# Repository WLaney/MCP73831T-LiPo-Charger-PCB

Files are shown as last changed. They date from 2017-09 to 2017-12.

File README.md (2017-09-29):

# MCP73831T-LiPo-Charger-PCB

This is a breakout board for the MCP73831T IC. The MCP73831T is a LiPo charging chip.

This board was desgined as part of the Sharkduino Project at The College of William and Mary, more information can be found at [sharkduino.com](http://www.sharkduino.com)

## License Information

This hardware is released under [Creative Commons ShareAlike 4.0 International](https://creativecommons.org/licenses/by-sa/4.0/).

It is derived from the [SparkFun LiPo Charger Basic](https://github.com/sparkfun/Lipo_Charger_Basic-microUSB/tree/V_1.0), desgined by SparkFun Electronics.

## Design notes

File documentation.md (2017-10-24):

# MCP73831T LiPo Charger

This board was designed by William Laney as part of the College of William and Mary's physics undergraduate research, 2017. 
Questions or concerns can be directed to William Laney at welaney@email.wm.edu

This is a LiPo battery chargining board based on the  MCP73831T IC. The MCP73831T  is a charging chip for 3.3V single cell lipo batteries. 

The chip is connected to a red LED. The LED is on while the battery is charging and turns off when the battery has completed its charge cycle.

Power enters the through a microUSB port on one side of the board, the LiPo to be charged in plugged into a JPL connector on the bottom of the board. The microUSB port and JPl connector are on oppistie sides of the board to more realistily simulate the set up of the Sharkduino system it is being developed for.

On the silk screen, IN corrosponds to the voltage from the microUSB port. OUT is voltage from the battery. GND is ground

All traces on this board are 0.016" and the vias have 0.034" drill holes. This is more than sufficient to handle the current through the traces. Right angles in the trace are avoid to help ensure data integrity.

Decoupling capacitors were added as near to the chips as possible to minimize noise to the chips. This is detailed in the relevant data sheets.

0805 package size is used for all passive components. This size was selected because I believe it to be a good compromise between size and ease of placement.

On October 5, 2017 six boards were ordered from OSHpark for \$4.90. This corresponds to \$0.81 per board.

## Assembily Information

Assemblie steps:
(please note that these steps represent what I beilive to be the optimal order of operations. They may not be. Addionaly not all boards were assembled in this way as I expermented with the order)

1. Applie solder paste for MCP73831T
2. Applie solder past for passive components
3. Applie solder past for microUSB port
4. Place MCP73831T
5. Place passive components
   * Start with components closest to the board and work inward
6. Place full board into solder reflow oven
7. Wipe down with isopropal alchohal 
8. Hand solder JPL connector onto the bottom of the board
9. Hand solder the through hole portions of the microUSB port
10. Check if board is shorted between GND and IN/OUT

## Notes/Feature Requests

*this information is subject to change with as more boards are assembled*

The microUSB port on the BOM does not match the land pattern on the board

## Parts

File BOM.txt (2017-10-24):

component/value, size, quanity, digikey part number
--------------------------------------------------------
MCP73831 IC, SC-74A/SOT-753, 1, MCP73831T-2ATI/OTCT-ND
JST Male, 2mm, 1, 455-1749-1-ND
USB micro SMD+TH, NA, 1, 609-4618-1-ND
4.7uF capacitor, 0805, 2, 490-3335-1-ND
330 resistor, 0805, 1, 311-330CRCT-ND
2k resistor, 0805, 1, 311-2.00KCRCT-ND
Red LED, 0603, 1, 754-1122-1-ND

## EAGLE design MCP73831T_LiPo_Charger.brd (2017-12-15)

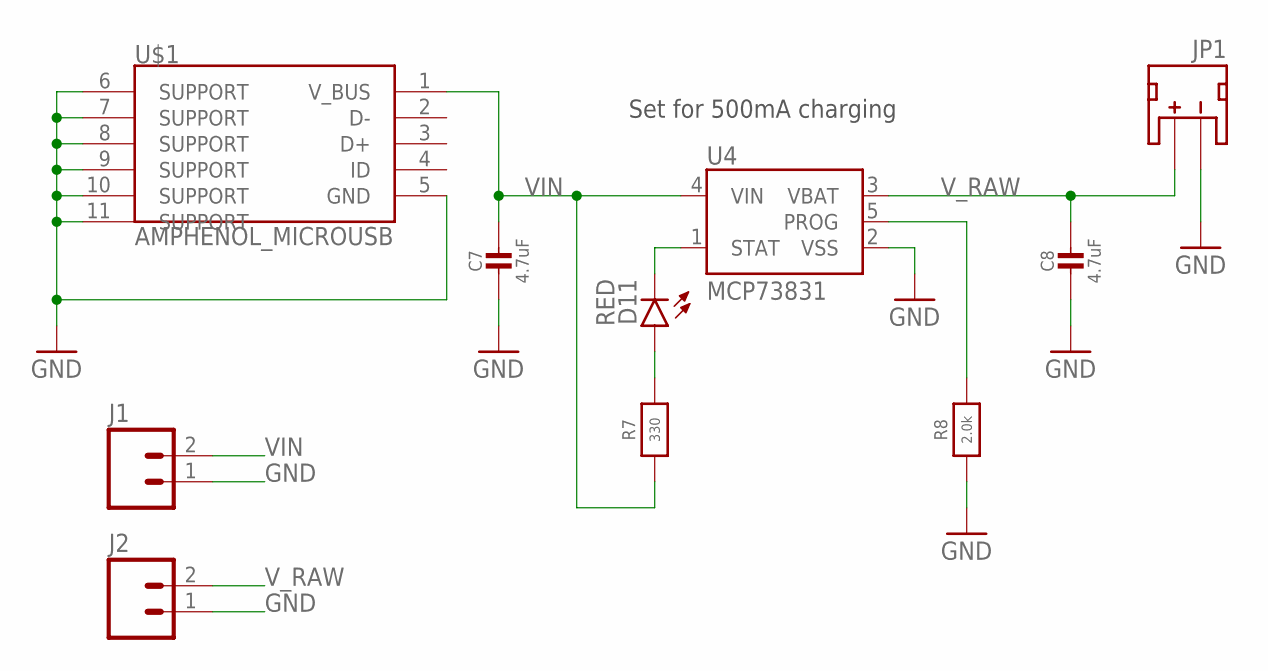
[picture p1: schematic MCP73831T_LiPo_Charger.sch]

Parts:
C7, C8: 4.7uF; 0805-NO
D11: RED; LED-0603
J1, J2: M02PTH; 1X02
JP1: JST; JST-2-SMD@1
R7: 330; _0805MP
R8: 2.0k; _0805MP
U4: MCP73831; SOT23-5
U$1: AMPHENOL_MICROUSB

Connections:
GND: C7.2, C8.2, J1.1, J2.1, JP1.1 (-), R8.1, U4.2 (VSS), U$1.5 (GND), U$1.6 (SUPPORT), U$1.7 (SUPPORT), U$1.8 (SUPPORT), U$1.9 (SUPPORT), U$1.10 (SUPPORT), U$1.11 (SUPPORT)
unnamed: D11.A, R7.2
PROG: R8.2, U4.5 (PROG)
STAT: D11.C, U4.1 (STAT)
VIN: C7.1, J1.2, R7.1, U4.4 (VIN), U$1.1 (V_BUS)
V_RAW: C8.1, J2.2, JP1.2 (+), U4.3 (VBAT)

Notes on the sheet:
Set for 500mA charging

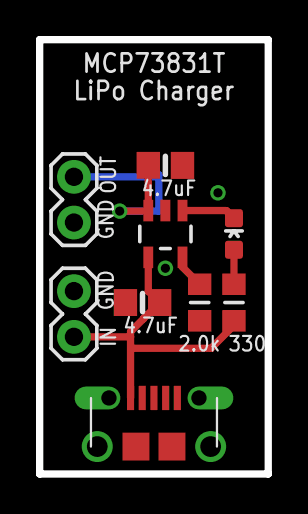
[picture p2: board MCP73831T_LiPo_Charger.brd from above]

Board: 2 copper layers, 12.7 x 24.1 mm, 10 parts (1 on the bottom side), 6 nets.

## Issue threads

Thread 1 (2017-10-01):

Determine the best micoUSB port

WLaney, 2017-10-01:
Currently the BOM has two options for the USB port, we should choose the best one.

WLaney, 2017-10-24:
The first choice is best

Closed 2017-10-24.

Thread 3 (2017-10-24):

heat managment

WLaney, 2017-10-24:
The chip/surrounding area on the board gets hot enough to be uncomfortable to touch. This heat needs to be quantified. Then we need to determine if it is a problem

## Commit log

2017-09-29 created schematic
    Moved charging circuit over from sharkduino V2.1
    Switched the uUSB port to the one used by adafruit on there [micro lipo charger](https://www.adafruit.com/product/1904)
    [MCP73831T_LiPo_Charger.sch]
2017-09-29 added headers to schematic
    [MCP73831T_LiPo_Charger.sch]
2017-09-30 inital layout
    [MCP73831T_LiPo_Charger.brd]
2017-09-30 added part silk lable
    [MCP73831T_LiPo_Charger.brd]
2017-09-30 put silk on tPlace
    [MCP73831T_LiPo_Charger.brd]
2017-09-30 finish silk
    [MCP73831T_LiPo_Charger.brd]
2017-10-01 silk updates
    [MCP73831T_LiPo_Charger.brd]
2017-10-01 created BOM
2017-10-01 silk changes for manufacturing
    [MCP73831T_LiPo_Charger.brd]
2017-10-02 increased via drill size to 0.02
    this puts the drill size in line with the sharkduino 2.x boards, and makes the
    sparkfun DRC happy
    [MCP73831T_LiPo_Charger.brd]
2017-10-24 updated BOM
2017-11-30 modified microUSB port
    [MCP73831T_LiPo_Charger.brd, MCP73831T_LiPo_Charger.sch]
2017-12-13 modified microusb port and lipo schematic
    [MCP73831T_LiPo_Charger.brd, MCP73831T_LiPo_Charger.sch]
2017-12-15 final changes for osh park order
    [MCP73831T_LiPo_Charger.brd]

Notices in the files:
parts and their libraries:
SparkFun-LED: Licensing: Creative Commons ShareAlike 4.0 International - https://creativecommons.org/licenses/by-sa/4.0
